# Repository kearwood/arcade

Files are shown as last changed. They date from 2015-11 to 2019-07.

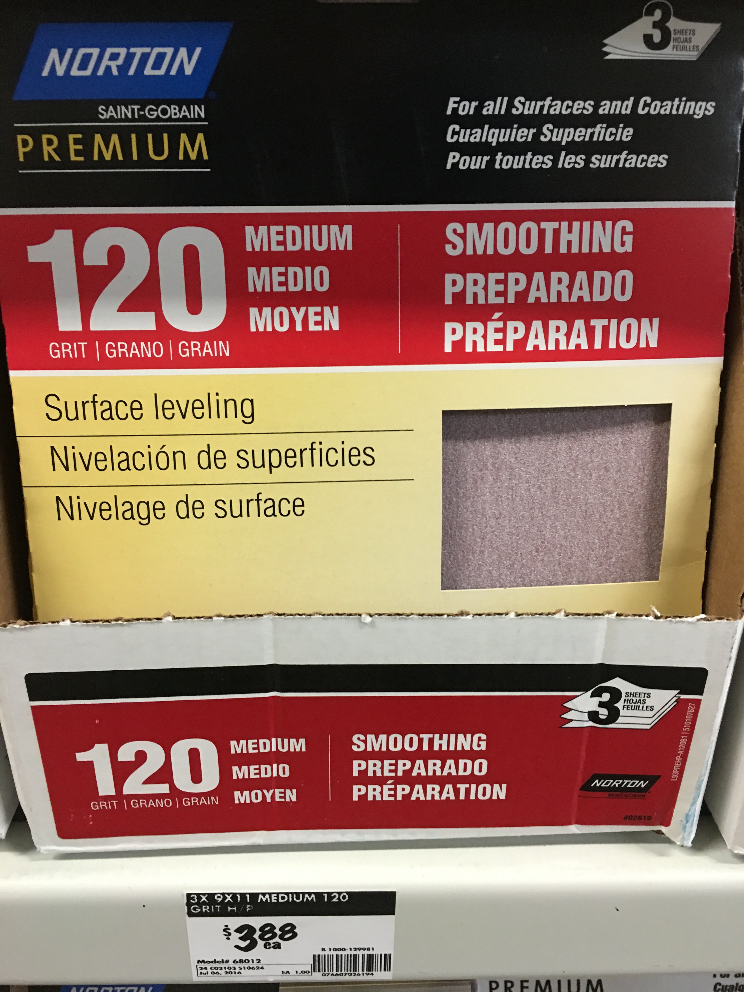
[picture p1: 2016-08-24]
base/sandpaper-120-grit.jpg

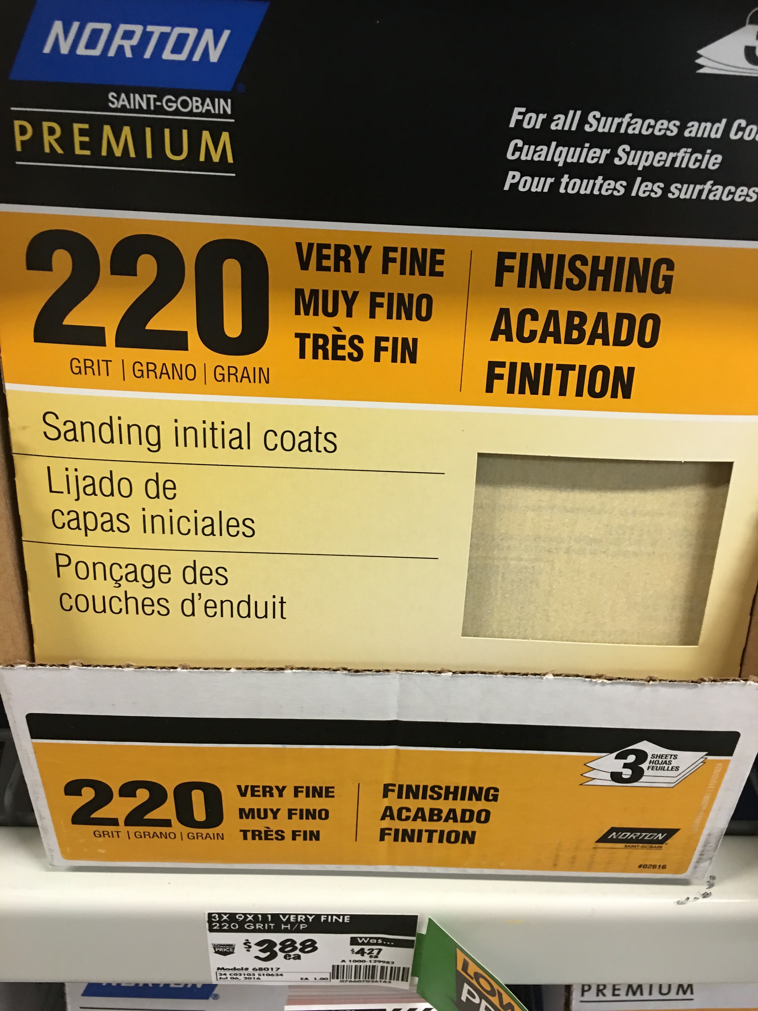
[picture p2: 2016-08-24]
base/sandpaper-220-grit.jpg

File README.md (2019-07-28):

# arcade
Arcade Controller for 2 Players

## Mark 1 Design
Mark 1 has a Sega button layout with two players and extra buttons for menu and coin operation.  8 buttons are included for each player in order to allow both 2x3 layouts (eg, Street Fighter) or 4x1 layouts (eg, NeoGeo).

## Mark 2 Design
Mark 2 adds a trackball and is a bit wider to accomodate it.

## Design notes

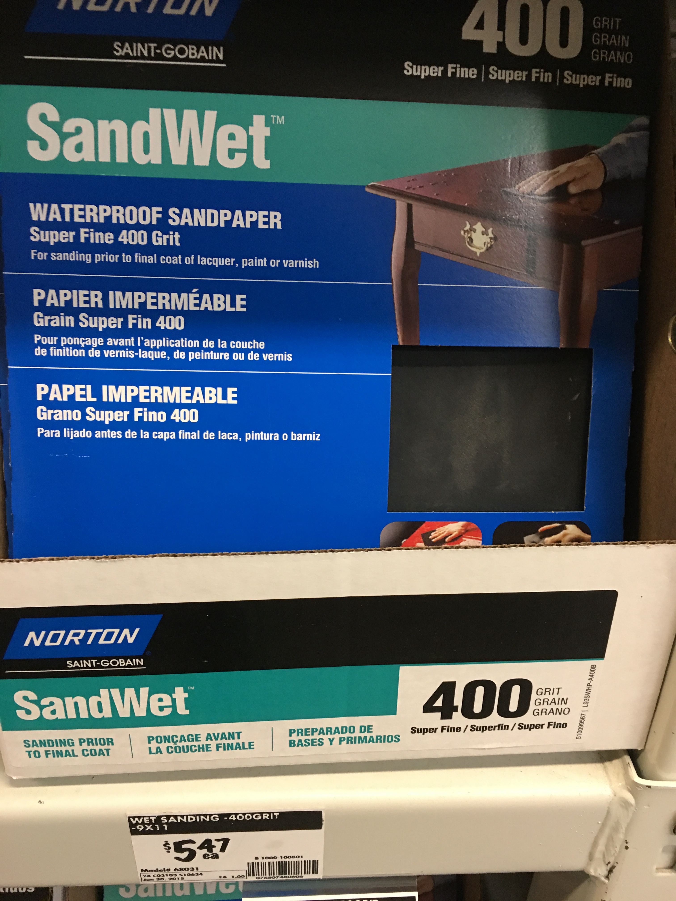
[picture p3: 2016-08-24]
base/sandpaper-400-grit-wet.jpg

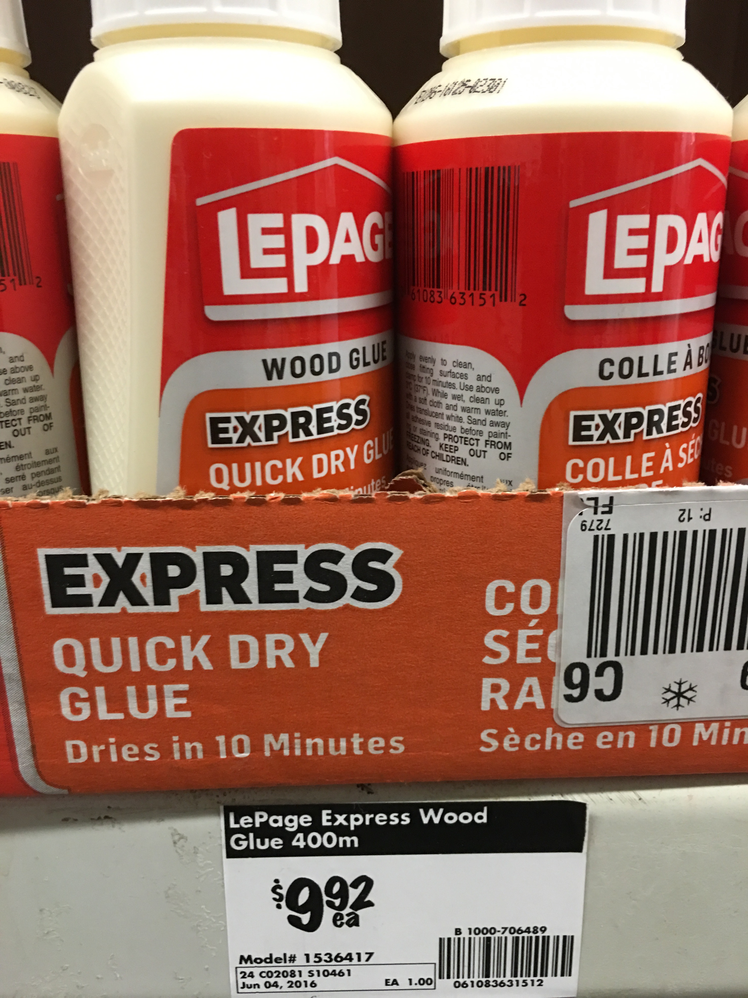
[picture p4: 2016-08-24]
base/quick-dry-wood-glue.jpg

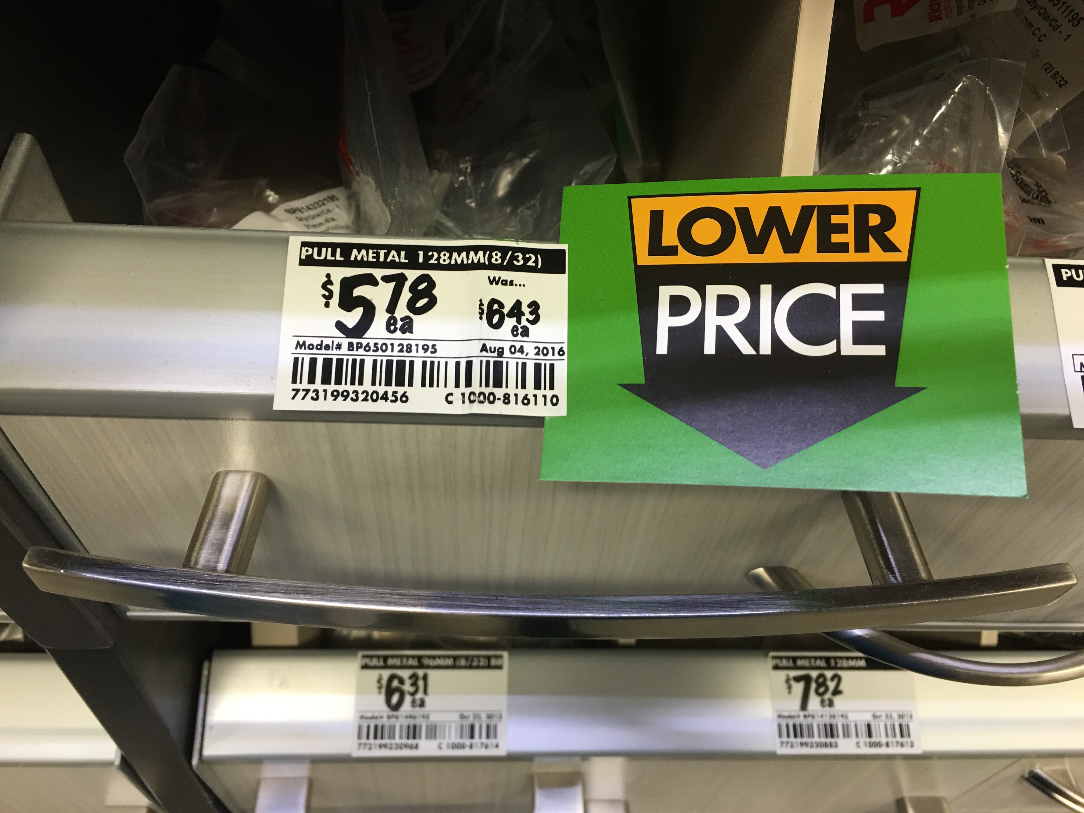
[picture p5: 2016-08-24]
base/handle.jpg

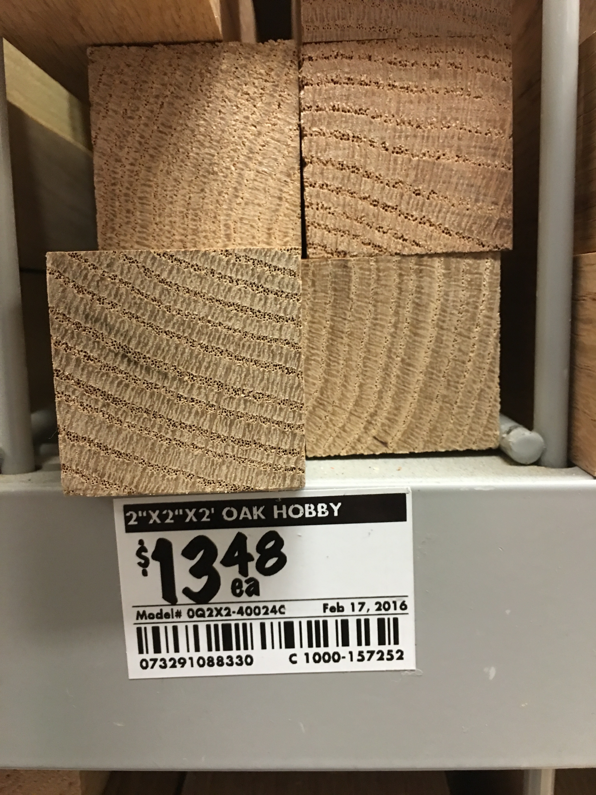
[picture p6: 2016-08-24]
base/oak-square-2x2x2.jpg

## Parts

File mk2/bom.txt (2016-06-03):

Bill of materials for arcade controller.

2 x Sanwa JLF-TP-8YT Joystick, with flat mounting plate and 5-pin wiring harness

4 x Sanwa LB-35 Balltop or “LB-35” compatible
  (Require 2, but recommend having spares as they can break, unscrew, be lost..)

5 x Sanwa OBSN 24mm buttons

16 x Sanwa OBSN 30mm buttons

1 x Ultimarc U-Trak trackball, with RGB Illumination kit and wiring harness

1 x Ultimarc Mini-PAC usb interface, with switch and trackball hardnesses

1 x Arduino for pcm controll of the trackball illumination.

1 x RaspberryPi (optional game host)

1 x Custom metal panel

1 x Custom wood case

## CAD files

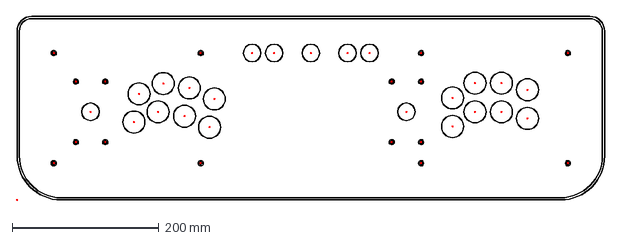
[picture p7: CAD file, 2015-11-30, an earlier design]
mk1/Arcade Panel.dxf
801.0 x 251.0 mm

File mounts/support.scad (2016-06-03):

// Temporary support stand-offs for the front panel
// until we have a case built.

// dimensions in millimetres.
wall = 15;
height = 70;
length = 120;
width = 90;
stud_surround = 24;

// Set arc smoothness limits for a better finish.
$fa = 3;
$fs = 1;

difference() {
  union() {
    cube([length, wall, height]);
    cube([wall, width, height]);
    intersection() {
      cube([length, length, height]);
      translate([wall, wall, 0]) {
        cylinder(r=wall + stud_surround/2, h=15);
      }
    }
  }
  translate([wall + stud_surround/2, wall + stud_surround/2, 0]) {
    cylinder(d=4, h = 32, center=true);
  }
}

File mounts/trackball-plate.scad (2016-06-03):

// Adaptor plate for mounting a trackball (U-Trak from ultimarc.com) on a metal plate.

// Dimensions in millimetres.
panel_thickness = 6;
thickness = 19-5-panel_thickness;

// Centre mount hole is 82mm, 86 with bezel.
hole = 87;

// Mounting studs are at the four corners.
size = 145;
stud_offset = size/2 * sqrt(2);
stud_surround = 24;
stud_thickness = max(15, thickness);

// Calculate approximately tangent circle for bracing.
web_thickness = min(thickness, 6);
web_offset = (pow(stud_offset,2) + pow(stud_surround/2,2) - pow(size/2,2)) /
                (2*size+2*stud_surround/2-2*sqrt(2)*size/2);
web_radius = 2*size - sqrt(2)*web_offset;

// Set arc smoothness limits for a better finish.
$fa = 3;
$fs = 1;

difference() {
  union() {
    // Start with a blank plate.
    cylinder(d=size, h=thickness, center=false);
    // Arms for mounting studs.
    for (angle = [0:90:270]) {
      rotate([0, 0, angle+45]) {
        translate([0, -stud_surround/2, 0]) {
          cube([stud_offset, stud_surround, thickness]);
        }
        translate([stud_offset, 0, 0]) {
          cylinder(d=stud_surround, h=stud_thickness);
        }
      }
    }
    // Bracing web between the arms.
    difference() {
      s = size + stud_surround;
      translate([0, 0, web_thickness/2]) {
        cube([s, s, web_thickness], center=true);
      }
      for (angle = [0:90:270]) {
        rotate([0, 0, angle]) {
          translate([size/2 + web_radius, 0, 0]) {
            cylinder(r=web_radius, h=2.2*web_thickness, center=true);
          }
        }
        rotate([0, 0, angle+45]) {
          translate([stud_offset+stud_surround/2, 0, 0]) {
            cylinder(d=stud_surround, h=2.2*web_thickness, center=true);
          }
        }
      }
    }
  }

  // Central mount hole for the trackball.
  cylinder(d=hole, h=2.2*thickness, center=true);
  // Trackball's through-hole screws are 5mm diameter.
  // Inserts are 6-7mm diameter, 7mm deep.
  for (angle = [0:90:270]) {
    rotate([0, 0, angle]) {
      translate([57.5, 0, thickness - 8]) {
        cylinder(d=7.1, h=thickness);
      }
      translate([57.5, 0, thickness - 1.7]) {
        cylinder(d=8, h=thickness);
      }
    }
  }
  // Panel mounting studs are 20mm M3.
  for (angle = [0:90:270]) {
    rotate([0,0,angle+45]) {
      translate([stud_offset, 0, 0]) {
        cylinder(d=4, h=2.2*stud_thickness, center=true);
      }
    }
  }
}

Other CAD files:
mk1/Arcade Panel.skp

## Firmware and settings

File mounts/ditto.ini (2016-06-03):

# Configure Slic3r 1.2.9 for Tinkerine Ditto+
gcode_flavor = reprap
bed_shape = 0x0,210x0,210x185,0x185
filament_diameter = 1.75
layer_height = 0.2
nozzle_diameter = 0.35
temperature = 220
first_layer_temperature = 220
filament_colour = #FFFFFF

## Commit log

2015-11-30 Initial dump to git
    [Arcade Panel.dxf, Arcade Panel.skp]
2016-03-06 Start laying out a trackball adaptor plate.
    [trackball-plate.scad]
2016-03-06 Add holes for trackball and screws.
    [trackball-plate.scad]
2016-03-06 Add holes for M3 mounting posts.
    Just guessing at 3.2mm diameter for M3 screws.
    [trackball-plate.scad]
2016-03-06 Abstract panel thickness.
    [trackball-plate.scad]
2016-03-06 Make insert holes blind instead of through.
    [trackball-plate.scad]
2016-03-06 Cut out around holes to reduce material.
    [trackball-plate.scad]
2016-03-06 Fix indent.
    [trackball-plate.scad]
2016-03-06 Add a makefile for stl generation.
2016-03-06 Add makefile rule for generating gcode.
    This is a minimal config for our Tinkrine Ditto+ printer,
    just the values that differ from the defaults.
    Note that 220C is the recommended print temperature for
    the recent tinkerine brand filament we're using, but that's
    considerably hotter than the 200C default I've been using
    so some verification may be needed. Could definitely use
    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
2016-03-06 Try 6mm holes for screw sleeves.
    This is the diameter (or 1/4 inch) which is recommended
    by the mounting instructions.
    [trackball-plate.scad]
2016-03-07 Set first-layer temperature as well.
    The documentation says this defaults to the main
    temperature setting, but instead it seems to default
    to the overall default of 200C.
2016-03-07 Make gcode depend on ditto.ini.
    This way we rebuild output files print after parameter changes.
2016-03-07 Bump screw sleeve holes after testing.
    6 mm is too small even for a press fit, probably because the plastic
    is harder than wood. Might work with a heated press, but we don't
    have one of those.
    From tests the correct size is somewhere between 7 and 8 mm.
    [trackball-plate.scad]
2016-03-07 Front panel is 6mm aluminum.
    [trackball-plate.scad]
2016-03-07 Move mounting stud.
    Generalize the offset to a variable so it can be shared between
    the surround and the through-hole.
    I remembered the dimension correctly, but forgot to account
    for the extra sqrt(2) for it being at 45 degrees relative
    to the other mounting holes.
    NB this breaks printability because it's outside the defined
    size envelope so the mounting holes aren't connected to the
    main ring. I need to update the connecting shapes.
    Also fix a dimension issue with the updated panel thickness.
    [trackball-plate.scad]
2016-03-08 Shrink sleeve holes.
    7.5 mm is loose and will not hold the sleeve. Try 7.1.
    [trackball-plate.scad]
2016-03-08 Connect stud holes with arms.
    This lets us print the design again. It would probably be better
    to have more connecting material for strength though.
    Also set finer arc subdivisions so we get less faceting in prints.
    [trackball-plate.scad]
2016-03-20 Add webbing between the arms for strength.
    Probably it's fine, this just looks pretty.
    [trackball-plate.scad]
2016-03-21 Try a smaller mount hole.
    It looks like the console plate is thick enough the bezel
    won't protrude into this piece.
    [trackball-plate.scad]
2016-03-22 Nope, bezel does protrude through the top plate.
    The 83 mm hole fit the trackball perfectly with no play,
    however.
    [trackball-plate.scad]
2016-03-22 Make panel-stud holes 4 mm diameter.
    Tests show this fits the M3 studs nicely.
    [trackball-plate.scad]
2016-03-28 Add a panel support piece for assembly staging.
    We need something to protect the parts and stand-offs until
    a complete case is available. Try printing corner pieces
    which can be bolted to an M3 stud.
    [support.scad]
2016-03-30 Adjust support dimensions a bit.
    Needs to be thicker to clear the trackball, and
    avoid overlap on the sides.
    [support.scad]
2016-03-31 Make stud surrounds thicker.
    15mm is a better match for the 20mm mounting studs.
    [trackball-plate.scad]
2016-03-31 Swap arms for easier printing.
    [support.scad]
2016-04-01 Deepen and countersink insert holes.
    This should allow flush mounting, as long as the plate
    isn't too thin.
    [trackball-plate.scad]
2016-04-01 Make the plate 2mm thinner.
    I want the trackball to project a bit more past the bezel.
    [trackball-plate.scad]
2016-04-14 Add brief materials list.
2016-06-03 Created mk2 folder
    [Arcade Panel.dxf, Arcade Panel.skp]
2016-06-03 Move 3d-printed parts into a separate directory.
    [support.scad, trackball-plate.scad]
2016-06-03 Move mk2 bill of materials into the correct project directory.
2016-06-03 Make gcode files directly.
    This is generally what we want, even if it would be a bit indirect
    for people using other printers.
2016-08-24 Added images of base materials
